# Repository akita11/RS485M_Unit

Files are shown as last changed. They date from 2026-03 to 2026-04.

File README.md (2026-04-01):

# RS485M Unit

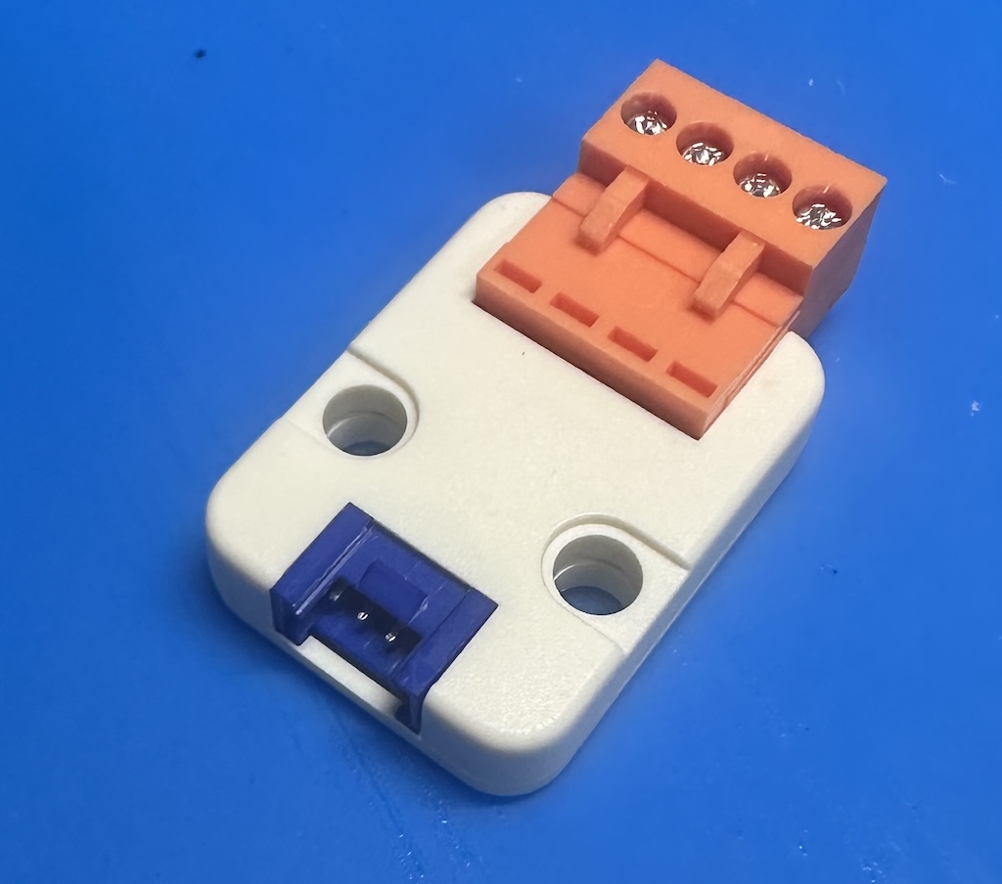
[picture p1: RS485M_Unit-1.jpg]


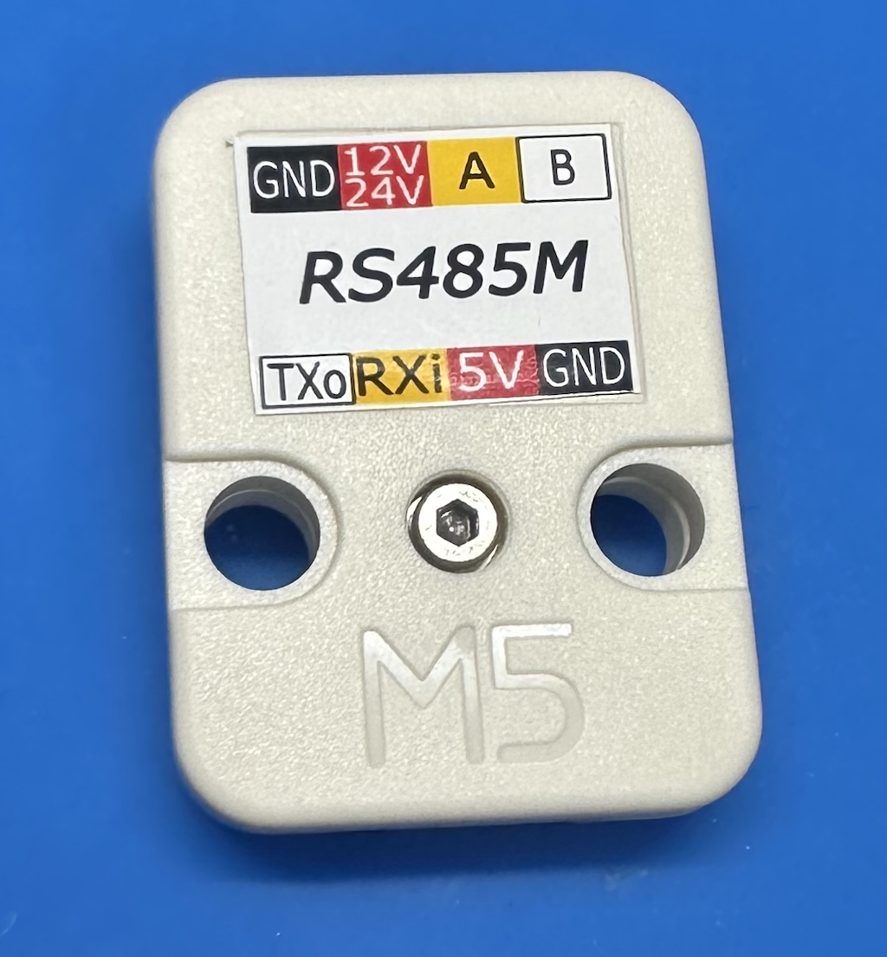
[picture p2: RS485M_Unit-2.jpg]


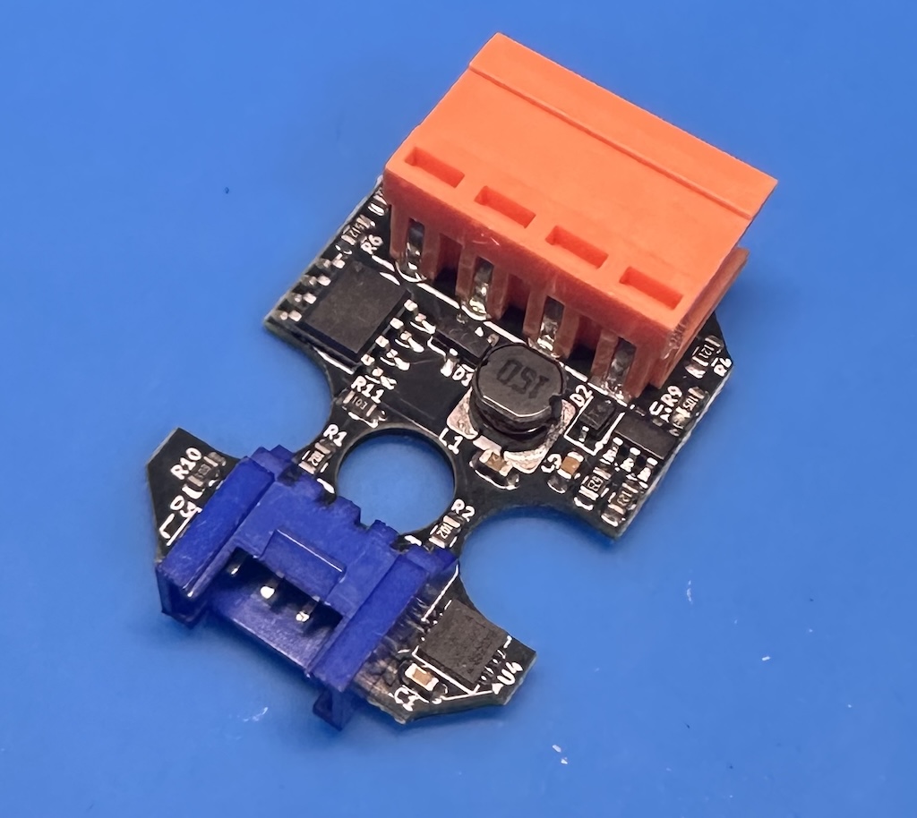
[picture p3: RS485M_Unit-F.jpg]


RS485規格の半二重シリアル通信を行うことができるUnitです。
Grove端子でM5Stackシリーズ等のマイコンと接続して使用します。

[M5Stack社のRS485 Unit](https://www.switch-science.com/products/6554)とは異なり、本来のRS485の通信仕様でマルチドロップの1:N通信トポロジを構成できます（詳細は後述）。
データを送信している期間のみ伝送路を送信駆動する制御を行います（通信速度は変更可能）。

伝送路側から最大24Vを供給してマイコン側に5Vを供給することができます。

理論上最大256台まで接続可能な低入力容量型のRS485ドライバを使用しています。

## RS485通信の基本構成と「M5Stack社のRS485 Unit」との相違点

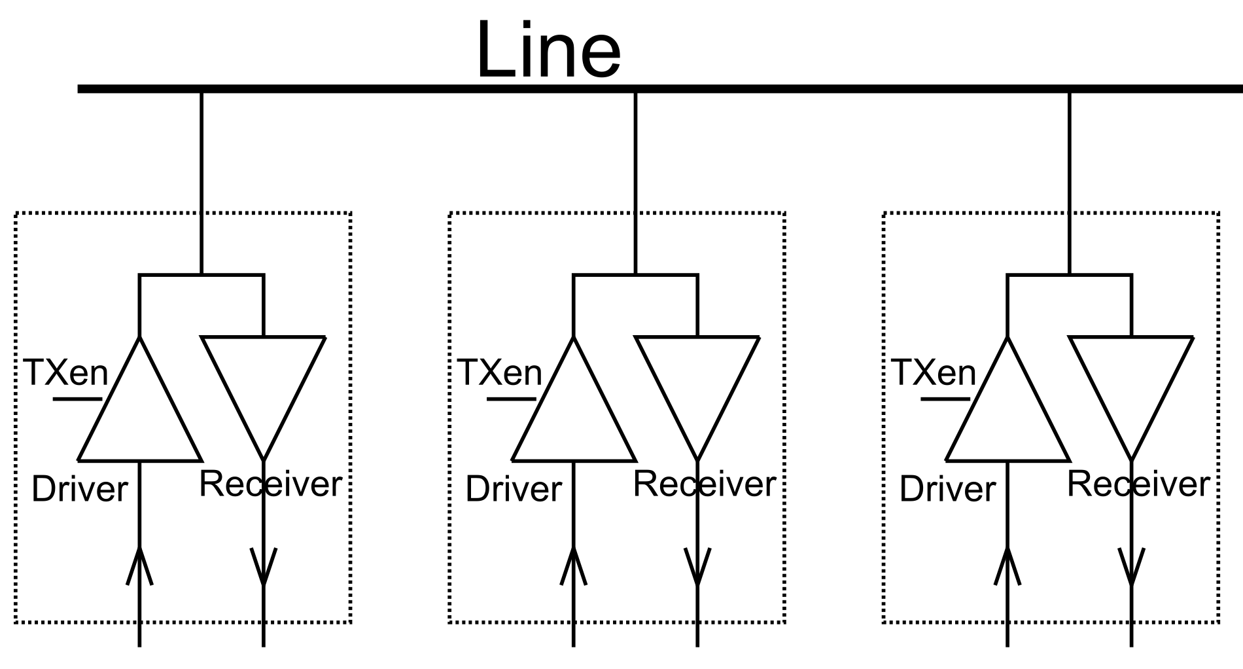
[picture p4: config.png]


RS485は、2本の伝送路(Line)を使ってシリアルデータ(UART)を送受信する規格です。
規格の詳細と、M5Stack社のRS485 Unitでの留意すべき点は[こちら](https://note.com/akita11/n/n0c082069f98c)を参照してください。

「M5Stack社のRS485 Unit」との相違点は以下です。
（以下のカッコ内の※以下は「M5Stack社のRS485 Unit」の仕様）

- 非送信時には伝送路が非駆動（※"1"で駆動）
- 送信時のみ伝送路を駆動、1バイト単位自動またはGPIOで制御（※常時"1"で駆動）
- 給電入力は48Vまで、24V給電時の過渡応答でも破損しにくい（※給電入力の絶対最大定格が30Vのため24V給電時の過渡応答で破損する場合がある）

## 使い方

基本的には[M5Stack社のRS485 Unit](https://www.switch-science.com/products/6554)と同じ使い方ですが、送信制御のみ異なり、以下の通りの仕様です。

なおJP5をショートすると伝送路の終端抵抗（120Ω）をONにできます。
またJP6とJP7をショートすると、伝送路のプルアップ・プルダウンを有効にできます（Aプルアップ、Bがプルダウン（5.1kΩ））。

### データ送信

データ送信時には、送信している期間のみDriverが自動的に有効となり、伝送路Lineを駆動します。

スタートビット検出から1バイト分（10bit分=STARTビット+データ8ビット+STOPビット）の時間だけ自動的にDriverが有効となり、伝送路にデータを送信します（伝送路を駆動中はLEDが点灯）。
通信方式はN81（8ビット・STOPビット1ビット、パリティなし）で固定です。
初期設定では通信速度は9600bpsです。

データ送信時にDriverを有効とする時間は、データ転送速度（ボーレート）に依存するため、後述の方法で変更できます

データ送信中は、Receiverは無効となり、データを受信しません。
JP8を2-3側に切り替えると、伝送路レシーバReceiverを常時有効に設定できますが、この場合は、自分のDriverが送信したデータを常時受信することになります。

### ピン配置

- p1: RXD（マイコン側の受信。本ユニットはRS485受信データの出力）
- p2: TXD（マイコン側の送信。本ユニットはRS485送信データの入力）
- p3: +5V
- p4: GND

### 伝送速度（ボーレート）の変更

Grove側からBREAK信号（一定時間以上、データ線を"L"に保持）することで、伝送速度変更モードに入り、LEDが点滅します。
この状態で、設定したい伝送速度（ボーレート）で以下のいずれか1バイトを送信することで、その波形から伝送速度を検出し、伝送速度の設定（Driverを有効とする時間）を変更します。
設定された伝送速度は電源を切っても保存されます。

- 'U' (0x55) : 1バイト伝送モード。1バイト伝送終了後の伝送路ドライバがDisableに戻ります。（LEDが3回点滅）
- '5' (0x35) : 連続伝送モード。送信開始語、一定時間データが送られなかった場合に伝送路ドライバがDisableに戻ります。（LEDが5回点滅）

なおBREAK信号は、PC用ターミナルソフトでも送出ができます（例えばTeraTermではAlt+B、MacのscreenコマンドではCtrl+A→Ctr+B）。
[Groveケーブル-USBシリアル接続ケーブル](https://www.switch-science.com/products/9460)などを使って、PCと接続して設定変更や送受信テストができます。

### 電源給電の設定

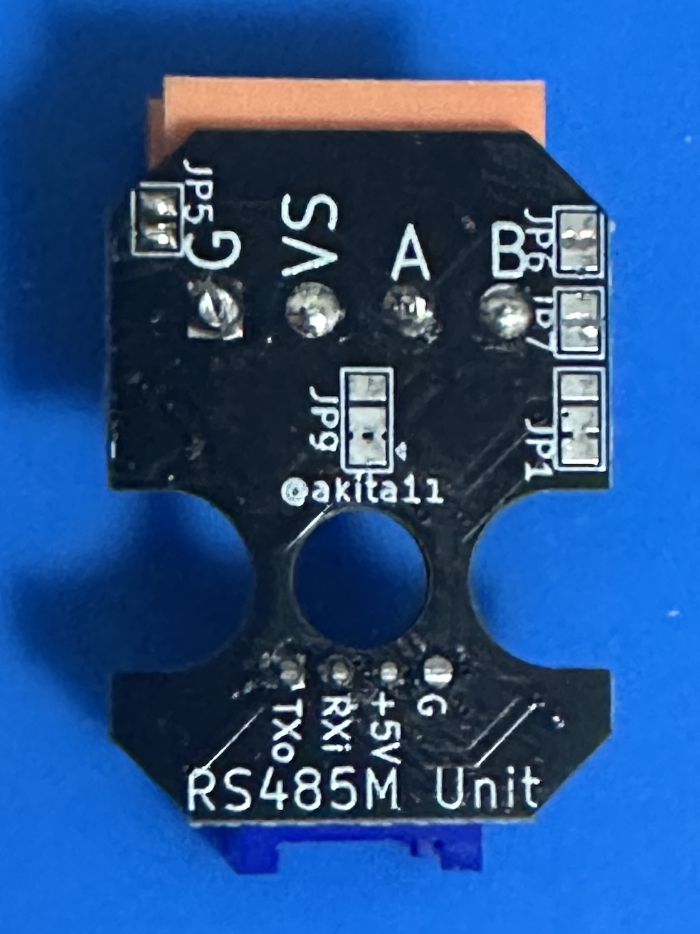
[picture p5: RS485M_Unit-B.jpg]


デフォルトでは、RS485ドライバは5V給電（外部12/24Vから生成した5V）ですが、以下のように変更できます。
なおGrove端子側から5Vを供給することもできます。

- JP9: 給電方法
  - 1-2間: 外部12/24Vから5Vを生成、本体とGroveへ供給（デフォルト）
  - 2-3間: 外部給電をそのまま本体・Groveへ接続（※この場合は外部からの給電電圧は5Vとしてください。5V以上の電圧を加えると破損する場合があります）

## Author

Junichi Akita (@akita11) / akita@ifdl.jp

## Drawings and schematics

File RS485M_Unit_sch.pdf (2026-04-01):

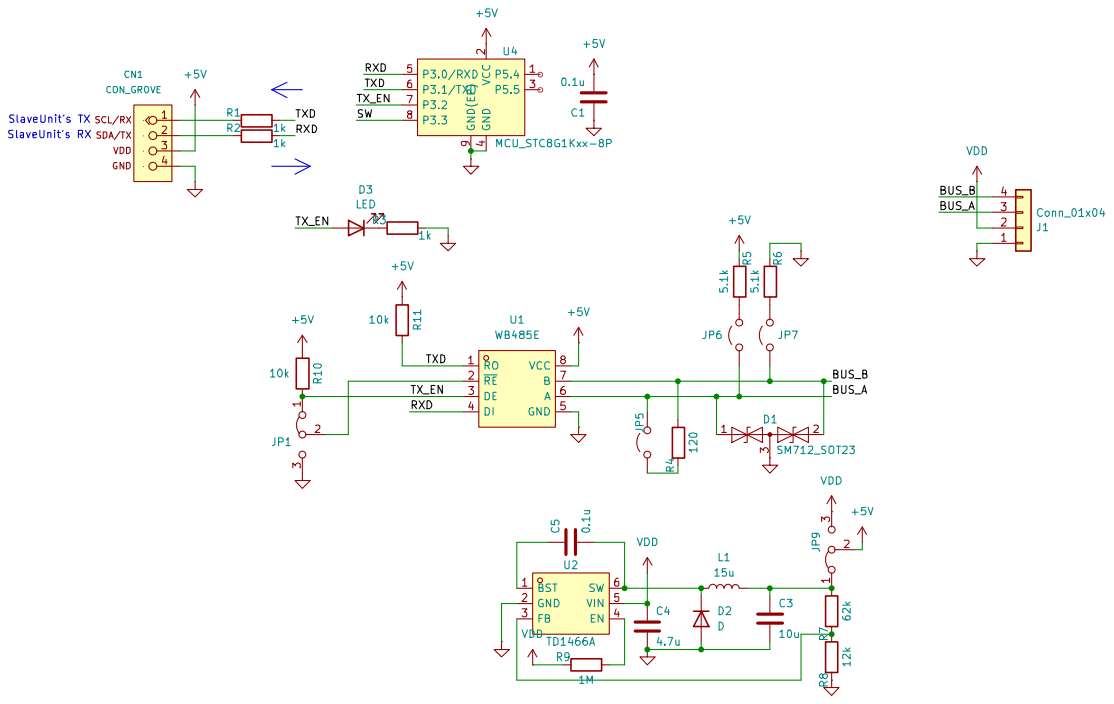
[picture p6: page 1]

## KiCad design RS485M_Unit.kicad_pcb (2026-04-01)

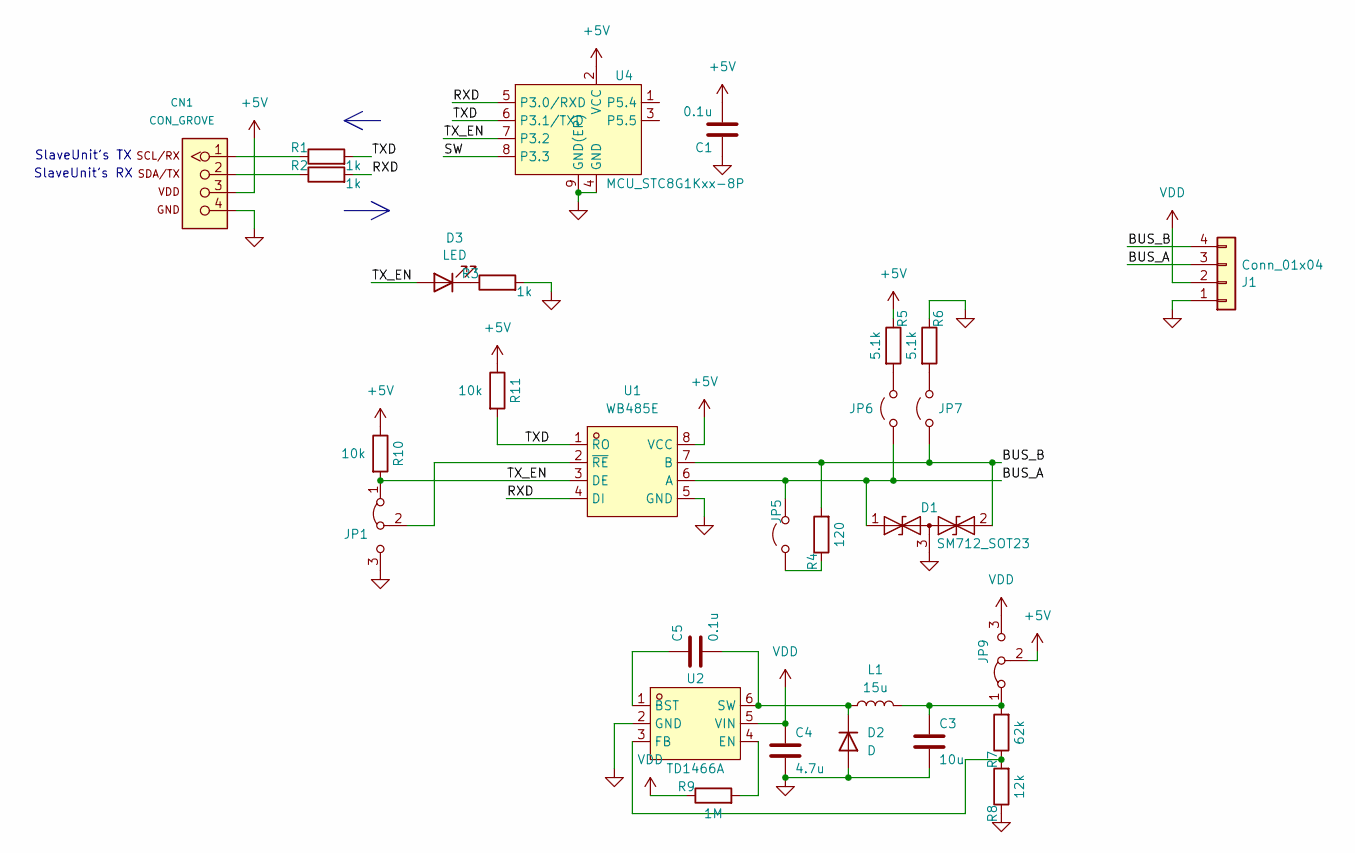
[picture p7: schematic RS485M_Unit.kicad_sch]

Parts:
C1, C5: 0.1u; C_0603_1608Metric; LCSC C14663
C3: 10u; C_0603_1608Metric; LCSC C19702
C4: 4.7u; C_0603_1608Metric; LCSC C167655
CN1: CON_GROVE; CON_GROVE_H
D1: SM712_SOT23; SOT-23; LCSC C5180237
D2: D; D_SOD-323F
D3: LED; LED_0603_1608Metric; LCSC C2286
J1: Conn_01x04; CON_HT396R_4P_hole0.8sq
JP1: Jumper_3_Bridged12; SolderJumper-3_P1.3mm_Bridged12_Pad1.0x1.5mm
JP5, JP6, JP7: Jumper_2_Open; SolderJumper-2_P1.3mm_Open_Pad1.0x1.5mm
JP9: Jumper_3_Bridged12; SolderJumper-3_P1.3mm_Bridged2Bar12_Pad1.0x1.5mm
L1: 15u; L_CD43; LCSC C5289403
R1, R2, R3: 1k; R_0603_1608Metric; LCSC C21190
R4: 120; R_0603_1608Metric; LCSC C286567
R5, R6: 5.1k; R_0603_1608Metric; LCSC C23186
R7: 62k; R_0603_1608Metric; LCSC C3017756
R8: 12k; R_0603_1608Metric; LCSC C3017713
R9: 1M; R_0603_1608Metric; LCSC C2907115
R10, R11: 10k; R_0603_1608Metric; LCSC C25804
U1: WB485E; SOIC-8_L5.0-W4.0-P1.27-LS6.0-BL; LCSC Part C42460582
U2: TD1466A; SOT-23-6_L2.9-W1.7-P0.95-LS2.8-BL; LCSC Part C51928156
U4: MCU_STC8G1Kxx-8P; DFN-8-1EP_3x3mm_P0.5mm_EP1.65x2.38mm; LCSC C915664

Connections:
+5V: C1.2, CN1.3, JP9.2 (C), R5.1, R10.1, R11.1, U1.8 (VCC), U4.2 (VCC)
/BUS_A: D1.1 (A1), J1.3, JP5.2 (B), JP6.1 (A), U1.6 (A)
/BUS_B: D1.2 (A2), J1.4, JP7.1 (A), R4.2, U1.7 (B)
/RXD: R2.2, U1.4 (DI), U4.5 (P3.0/RXD)
/SW: U4.8 (P3.3)
/TXD: R1.2, R11.2, U1.1 (RO), U4.6 (P3.1/TXD)
/TX_EN: D3.2 (A), JP1.1 (A), R10.2, U1.3 (DE), U4.7 (P3.2)
GND: C1.1, C3.2, C4.2, CN1.4, D1.3 (common), D2.2 (A), J1.1, JP1.3 (B), R3.2, R6.1, R8.1, U1.5 (GND), U2.2 (GND), U4.4 (GND), U4.9 (GND(EP))
unnamed: CN1.1, R1.1
unnamed: CN1.2, R2.1
unnamed: C5.2, D2.1 (K), L1.1, U2.6 (SW)
unnamed: D3.1 (K), R3.1
unnamed: JP1.2 (C), U1.2 (~RE)
unnamed: JP5.1 (A), R4.1
unnamed: JP6.2 (B), R5.2
unnamed: JP7.2 (B), R6.2
unnamed: C3.1, JP9.1 (A), L1.2, R7.2
unnamed: C5.1, U2.1 (BST)
unnamed: R9.2, U2.4 (EN)
unnamed: R7.1, R8.2, U2.3 (FB)
VDD: C4.1, J1.2, JP9.3 (B), R9.1, U2.5 (VIN)

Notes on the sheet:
SlaveUnit's TX
SlaveUnit's RX

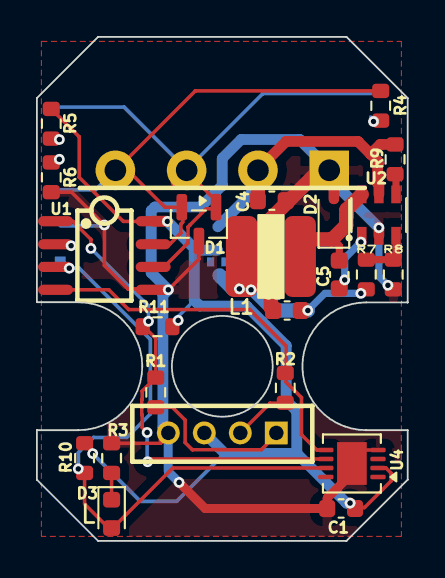
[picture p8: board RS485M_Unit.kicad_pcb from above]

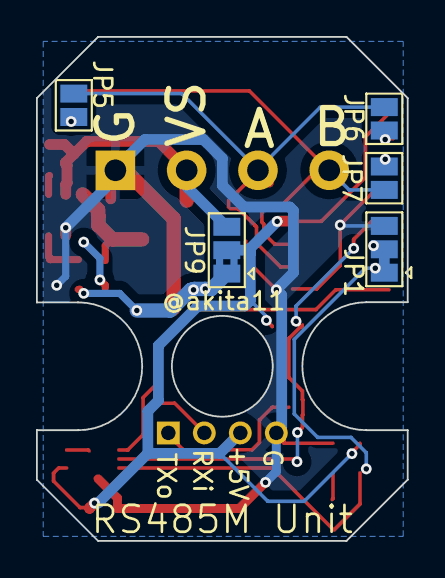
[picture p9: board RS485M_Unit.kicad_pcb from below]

Board: 2 copper layers, 20.6 x 28.0 mm, 29 parts (5 on the bottom side), 20 nets.

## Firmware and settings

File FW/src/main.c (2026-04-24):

#include <stdint.h>
#include "fw_reg_stc8g.h"

// STC8G1K08A-36I-DFN8 (ROM=8kB)
// P3.0: RXD (UART1 receive)
// P3.2: TX_EN (RS485 transmit enable, push-pull output)

#define FOSC 11059200UL

//#define DEBUG  // Uncomment to enable UART debug output during auto-baud detection

// Pin definitions
#define pinRXD  P30  // P3.0
#define pinTXEN P32  // P3.2

// SCON.7 is FE when SMOD0=1 (shares bit with SM0)
#define FE SM0

// EEPROM (IAP) definitions
#define IAP_ADDR_BASE   0x0000
#define IAP_MAGIC       0xA5
#define IAP_MAGIC2      0x5A
// Layout: [0]=MAGIC [1]=MAGIC2 [2]=bit_period_H [3]=bit_period_L [4]=txen_per_byte

// Baud rate detection timeout
#define BAUD_DETECT_TIMEOUT_MS  5000UL
#define TIMER0_OVERFLOW_MS      6UL
#define BAUD_TIMEOUT_OVERFLOWS  (BAUD_DETECT_TIMEOUT_MS / TIMER0_OVERFLOW_MS)
#define TOGGLE_PERIOD_OVERFLOWS  (500UL / TIMER0_OVERFLOW_MS)   // ~83 overflows ≈ 0.5 second

// Global variables
volatile uint16_t bit_period = FOSC / 9600;  // initial: 1152 SYSclk per bit
volatile uint8_t txen_per_byte = 1;          // 1: per-byte mode, 0: per-packet mode
volatile uint16_t baud_detect_timeout_counter = 0;
volatile uint8_t baud_detect_in_progress = 0;
volatile uint8_t do_auto_baud = 0;

void delay_cycles(uint16_t cycles)
{
  CL = 0;
  CH = 0;
  CR = 1;
  while (((uint16_t)CH << 8 | CL) < cycles);
  CR = 0;
}

void delay_ms(uint16_t ms)
{
  // 1ms ~ 11059 SYSclk cycles (@ 11.0592MHz)
  while (ms--) {
    delay_cycles(11059);
  }
}

// IAP (EEPROM) functions
void iap_idle(void)
{
  IAP_CONTR = 0;
  IAP_CMD = 0;
  IAP_TRIG = 0;
  IAP_ADDRH = 0x80;  // point to non-existent address
  IAP_ADDRL = 0;
}

uint8_t iap_read(uint16_t addr)
{
  IAP_CONTR = 0x80;      // IAPEN=1
  IAP_TPS = 11;          // FOSC=11.0592MHz -> 11
  IAP_CMD = 1;           // read
  IAP_ADDRH = addr >> 8;
  IAP_ADDRL = addr & 0xFF;
  IAP_TRIG = 0x5A;
  IAP_TRIG = 0xA5;
  NOP();
  {
    uint8_t val = IAP_DATA;
    iap_idle();
    return val;
  }
}

void iap_write(uint16_t addr, uint8_t dat)
{
  IAP_CONTR = 0x80;
  IAP_TPS = 11;
  IAP_CMD = 2;           // write
  IAP_ADDRH = addr >> 8;
  IAP_ADDRL = addr & 0xFF;
  IAP_DATA = dat;
  IAP_TRIG = 0x5A;
  IAP_TRIG = 0xA5;
  NOP();
  iap_idle();
}

void iap_erase(uint16_t addr)
{
  IAP_CONTR = 0x80;
  IAP_TPS = 11;
  IAP_CMD = 3;           // erase (512-byte sector)
  IAP_ADDRH = addr >> 8;
  IAP_ADDRL = addr & 0xFF;
  IAP_TRIG = 0x5A;
  IAP_TRIG = 0xA5;
  NOP();
  iap_idle();
}

void eeprom_save_baud(void)
{
  EA = 0;
  iap_erase(IAP_ADDR_BASE);
  iap_write(IAP_ADDR_BASE + 0, IAP_MAGIC);
  iap_write(IAP_ADDR_BASE + 1, IAP_MAGIC2);
  iap_write(IAP_ADDR_BASE + 2, bit_period >> 8);
  iap_write(IAP_ADDR_BASE + 3, bit_period & 0xFF);
  iap_write(IAP_ADDR_BASE + 4, txen_per_byte);
  EA = 1;
}

void eeprom_load_baud(void)
{
  if (iap_read(IAP_ADDR_BASE + 0) == IAP_MAGIC &&
      iap_read(IAP_ADDR_BASE + 1) == IAP_MAGIC2) {
    uint16_t bp = ((uint16_t)iap_read(IAP_ADDR_BASE + 2) << 8)
                | iap_read(IAP_ADDR_BASE + 3);
    // Validate: FOSC/115200 <= bp <= FOSC/300
    if (bp < (uint16_t)(FOSC / 115200UL) || bp > (uint16_t)(FOSC / 300UL)) return;
    bit_period = bp;
    uint8_t mode = iap_read(IAP_ADDR_BASE + 4);
    if (mode <= 1) txen_per_byte = mode;
    uint16_t reload = 65536U - (bit_period / 4U);
    TH1 = reload >> 8;
    TL1 = reload & 0xFF;
  }
}

#ifdef DEBUG
// UART debug output helpers
void uart_send_byte(uint8_t dat)
{
  uint16_t tout;
  SBUF = dat;
  for (tout = 60000U; !TI && tout; tout--);
  if (!TI) {
    // TI never set: Timer2/UART TX broken -> blink P3.2 rapidly as error signal
    while (1) {
      uint16_t _d;
      pinTXEN ^= 1;
      for (_d = 0; _d < 5000; _d++) NOP();  // ~500us per half-cycle -> ~1kHz blink
    }
  }
  TI = 0;
}

void uart_send_string(const char *str)
{
  while (*str) {
    uart_send_byte(*str++);
  }
}

void uart_send_hex_byte(uint8_t val)
{
  const char hex[] = "0123456789ABCDEF";
  uart_send_byte(hex[val >> 4]);
  uart_send_byte(hex[val & 0x0F]);
}

void uart_send_hex_word(uint16_t val)
{
  uart_send_hex_byte(val >> 8);
  uart_send_hex_byte(val & 0xFF);
}
#endif /* DEBUG */

void auto_baud_detect(void);

// INT4 ISR: P3.0 falling edge (start bit detection)
void INT4_ISR(void) __interrupt (16)
{
  pinTXEN = 1;
  AUXINTIF &= ~0x40;  // clear INT4 interrupt flag
  INTCLKO &= ~0x40;   // disable INT4
#ifdef DEBUG
  uart_send_byte('I');  // INT4 fired
#endif

  if (!txen_per_byte) {
    // Packet mode: stop timeout timer (next byte arrived in time)
    TR0 = 0;
  }
}

// Timer0 ISR: packet timeout OR baud detection timeout
void Timer0_ISR(void) __interrupt (1)
{
  if (baud_detect_in_progress) {
    // Baud detection timeout mode
    baud_detect_timeout_counter++;
    if (baud_detect_timeout_counter >= BAUD_TIMEOUT_OVERFLOWS) {
      TR0 = 0;  // Stop timer when timeout reached
    }
    // Note: Timer continues counting until timeout is reached
  } else {
    // Normal packet timeout mode
    TR0 = 0;
    if (!txen_per_byte) {
      pinTXEN = 0;
    }
  }
}

// UART1 ISR: RI or FE
void UART1_ISR(void) __interrupt (4)
{
  volatile uint8_t dummy;
  if (FE) {
    FE = 0;
    dummy = SBUF;
    (void)dummy;
    // BREAK = FE + received 0x00 + RXD still Low
    if (dummy == 0x00 && pinRXD == 0) {
#ifdef DEBUG
      uart_send_byte('B');  // BREAK detected → do_auto_baud
#endif
      pinTXEN = 0;
      INTCLKO &= ~0x40;  // disable INT4
      do_auto_baud = 1;  // defer to main loop (Timer0 ISR can't run in ISR context)
      return;            // return immediately; INT4 re-enabled by auto_baud_detect()
    }
#ifdef DEBUG
    uart_send_byte('F');  // FE (non-BREAK)
#endif
    // Non-BREAK FE: re-enable INT4
    pinTXEN = 0;
    AUXINTIF &= ~0x40;
    INTCLKO |= 0x40;
    return;
  }
  if (RI) {
    RI = 0;
    dummy = SBUF;       // read received data
    (void)dummy;
#ifdef DEBUG
    uart_send_byte('R');  // RI fired
#endif

    if (txen_per_byte) {
      // Per-byte mode: turn off TX_EN, re-enable INT4
      // Note: delay removed - RI fires at mid-stop-bit, sufficient for TX_EN deassertion
      pinTXEN = 0;
      AUXINTIF &= ~0x40;
      INTCLKO |= 0x40;
#ifdef DEBUG
      uart_send_byte('X');  // per-byte: TXen cleared
#endif
    } else {
#ifdef DEBUG
      uart_send_byte('P');  // per-packet path
#endif
      // Per-packet mode: re-enable INT4, start timeout timer
      AUXINTIF &= ~0x40;
      INTCLKO |= 0x40;

      // Reconfigure Timer0 for packet timeout (1.5 bit period)
      {
        uint16_t timeout = bit_period + (bit_period >> 1);  // 1.5 * bit_period
        uint16_t reload = 65536 - timeout;
        TH0 = reload >> 8;
        TL0 = reload & 0xFF;
      }
      TF0 = 0;
      TR0 = 1;
    }
  }
}

// Auto-baud detection using BREAK + single byte (0x55/0x35) pattern
// Measures 5 bit periods, reads D5/D6 to determine mode, blinks LED (3 or 5 times), then applies baud rate
void auto_baud_detect(void)
{
  uint16_t t_start, t_end;
  uint16_t old_bit_period = bit_period;
  uint8_t old_txen_per_byte = txen_per_byte;
#ifdef DEBUG
  uint8_t bit_period_measured = 0;  // Track if bit_period was measured
  uint8_t d5d6_measured = 0;        // Track if D5/D6 were read
#endif
  uint8_t d5_bit = 0;               // D5 bit value
  uint8_t d6_bit = 0;               // D6 bit value
  uint16_t last_toggle_counter = 0;

  REN = 0;
  INTCLKO &= ~0x40;
  pinTXEN = 1;  // Hold TXEN during baud rate measurement
  TR0 = 0;

  // Configure Timer0 for 5-second baud detection timeout
  baud_detect_in_progress = 1;
  baud_detect_timeout_counter = 0;
  TH0 = 0;
  TL0 = 0;
  TF0 = 0;
  TR0 = 1;  // Start timeout timer

  TR1 = 0;           // Stop Timer1 UART clock before reconfiguring for measurement

  // Timer1: 16-bit free-run, 1T mode
  TMOD = (TMOD & 0x0F) | 0x00;
  AUXR |= 0x40;  // T1x12=1

  TH1 = 0; TL1 = 0;
  TF1 = 0;
  TR1 = 1;

  // Wait for BREAK to end (RXD goes high)
  while (pinRXD == 0) {
    if (baud_detect_timeout_counter >= BAUD_TIMEOUT_OVERFLOWS) {
      goto abort;
    }
  }

  // Wait for falling edge (start bit)
  while (pinRXD == 1) {
    if (baud_detect_timeout_counter >= BAUD_TIMEOUT_OVERFLOWS) goto abort;
    if ((uint16_t)(baud_detect_timeout_counter - last_toggle_counter) >= TOGGLE_PERIOD_OVERFLOWS) {
      pinTXEN ^= 1;  // Toggle every ~1 second to show loop is running
      last_toggle_counter = baud_detect_timeout_counter;
    }
  }
  t_start = ((uint16_t)TH1 << 8) | TL1;

  // Measure 5 bit periods: S(0)->D0(1)->D1(0)->D2(1)->D3(0)->D4(1)
  // S(0)→D0(1)
  while (pinRXD == 0) {
    if (baud_detect_timeout_counter >= BAUD_TIMEOUT_OVERFLOWS) goto abort;
  }
  // D0(1)→D1(0)
  while (pinRXD == 1) {
    if (baud_detect_timeout_counter >= BAUD_TIMEOUT_OVERFLOWS) goto abort;
  }
  // D1(0)→D2(1)
  while (pinRXD == 0) {
    if (baud_detect_timeout_counter >= BAUD_TIMEOUT_OVERFLOWS) goto abort;
  }
  // D2(1)→D3(0)
  while (pinRXD == 1) {
    if (baud_detect_timeout_counter >= BAUD_TIMEOUT_OVERFLOWS) goto abort;
  }
  // D3(0)→D4(1)
  while (pinRXD == 0) {
    if (baud_detect_timeout_counter >= BAUD_TIMEOUT_OVERFLOWS) goto abort;
  }

  // Capture t_end; compute D5/D6 sample thresholds with shifts BEFORE expensive division
  t_end = ((uint16_t)TH1 << 8) | TL1;
  {
    uint16_t span = t_end - t_start;               // = 5T (subtraction only, ~2 cycles)
    uint16_t thr_d5 = (span >> 2) + (span >> 4);  // = 5/16 * span ≈ 1.5625T (within D5 window)
    uint16_t thr_d6 = span >> 1;                  // = 1/2 * span = 2.5T (exact D6 midpoint)
    uint16_t now_t;

    // Wait until middle of D5 bit period
    do {
      if (baud_detect_timeout_counter >= BAUD_TIMEOUT_OVERFLOWS) goto abort;
      now_t = ((uint16_t)TH1 << 8) | TL1;
    } while ((uint16_t)(now_t - t_end) < thr_d5);
    d5_bit = pinRXD;

    // Wait until middle of D6 bit period
    do {
      if (baud_detect_timeout_counter >= BAUD_TIMEOUT_OVERFLOWS) goto abort;
      now_t = ((uint16_t)TH1 << 8) | TL1;
    } while ((uint16_t)(now_t - t_end) < thr_d6);
    d6_bit = pinRXD;

    // Compute bit_period AFTER timing-critical sampling section
    bit_period = span / 5;
#ifdef DEBUG
    bit_period_measured = 1;
#endif
  }
#ifdef DEBUG
  d5d6_measured = 1;  // Mark as measured
#endif

  // Validate bit pattern and set mode
  if (d5_bit == 0 && d6_bit == 1) {
    // Pattern 01 → 0x55 → per-byte mode
    txen_per_byte = 1;
  } else if (d5_bit == 1 && d6_bit == 0) {
    // Pattern 10 → 0x35 → per-packet mode
    txen_per_byte = 0;
  } else {
    // Invalid pattern → abort
    goto abort;
  }

  // Stop Timer1 (measurement done)
  TR1 = 0;

  // Restore Timer1 for UART baud at old bit_period (needed for BP_PRE debug output)
  {
    uint16_t _r = 65536U - (old_bit_period / 4U);
    TH1 = _r >> 8;
    TL1 = _r & 0xFF;
    TR1 = 1;
  }

  // Stop timeout timer before blinking
  TR0 = 0;
  baud_detect_in_progress = 0;

  // Blink pinTXEN: 3 times for per-byte mode (0x55), 5 times for per-packet mode (0x35)
  // (100ms ON, 100ms OFF)
  {
    uint8_t i;
    uint8_t blink_count = txen_per_byte ? 3 : 5;  // 3 for mode=1, 5 for mode=0
    for (i = 0; i < blink_count; i++) {
      pinTXEN = 1;
      delay_ms(100);
      pinTXEN = 0;
      delay_ms(100);
    }
  }

  // Send BP_PRE at old baud rate for diagnosis (before Timer2 is updated)
#ifdef DEBUG
  uart_send_string("BP_PRE:");
  uart_send_hex_word(bit_period);
  uart_send_string("\r\n");
#endif

  // Apply new baud rate to Timer1
  {
    uint16_t reload = 65536U - (bit_period / 4U);
    TH1 = reload >> 8;
    TL1 = reload & 0xFF;
    // TR1 already running; new reload takes effect at next overflow
  }

  // Send all debug messages at new baud rate
#ifdef DEBUG
  uart_send_string("START\r\n");
  uart_send_string("BP:");
  uart_send_hex_word(bit_period);
  uart_send_string("\r\n");
  uart_send_string("D56:");
  uart_send_hex_byte(d5_bit);
  uart_send_hex_byte(d6_bit);
  uart_send_string("\r\n");
  uart_send_string("OK:MODE=");
  uart_send_hex_byte(txen_per_byte);
  uart_send_string("\r\n");
#endif

  // Save to EEPROM
  eeprom_save_baud();
  goto resume;

abort:
  // CRITICAL: Turn off TXEN immediately to fix timeout issue
  pinTXEN = 0;

  // Stop timers
  TR0 = 0;
  TR1 = 0;
  baud_detect_in_progress = 0;

  // Restore Timer1 for UART baud at old bit_period (for abort debug output)
  {
    uint16_t _r = 65536U - (old_bit_period / 4U);
    TH1 = _r >> 8;
    TL1 = _r & 0xFF;
    TR1 = 1;
  }

  // Display measured bit_period BEFORE restoring old value (UART still at old baud rate)
#ifdef DEBUG
  if (bit_period_measured) {
    uart_send_string("BP:");
    uart_send_hex_word(bit_period);
    uart_send_string("\r\n");
  }
#endif

  // Restore previous baud rate and mode
  bit_period = old_bit_period;
  txen_per_byte = old_txen_per_byte;

  // Send all debug messages at restored baud rate
#ifdef DEBUG
  uart_send_string("START\r\n");

  if (!bit_period_measured) {
    uart_send_string("BP:NONE\r\n");
  }

  if (d5d6_measured) {
    uart_send_string("D56:");
    uart_send_hex_byte(d5_bit);
    uart_send_hex_byte(d6_bit);
    uart_send_string("\r\n");
  } else {
    uart_send_string("D56:NONE\r\n");
  }

  uart_send_string("ABORT:TO=");
  uart_send_hex_word(baud_detect_timeout_counter);
  uart_send_string("\r\n");
#endif

resume:
  // Resume normal operation
  REN = 1;
  pinTXEN = 0;
  AUXINTIF &= ~0x40;
  INTCLKO |= 0x40;  // re-enable INT4
}

void main(void)
{
  // GPIO: P3.2 quasi-bidirectional (HiZ) initially; push-pull set after TX pin is finalized
#ifdef DEBUG
  P3M1 = 0x00;
  P3M0 = 0x02;  // P3.1 push-pull (TXD for debug); P3.2 quasi-bidirectional for now
  P3M0 |= 0x04; // P3.2 push-pull (TXen) - set after P3.1 push-pull confirmed
#else
  P3M1 = 0x02;  // P3.1 high-Z input
  P3M0 = 0x00;  // P3.2 quasi-bidirectional; push-pull set after TX HiZ confirmed (below)
#endif
  P5M1 = 0x00;
  P5M0 = 0x00;  // P5.4, P5.5 quasi-bidirectional
  pinTXEN = 0;

  // Pull-up on unused pins: P3.1, P3.3, P5.4, P5.5
  P_SW2 |= 0x80;  // enable extended SFR access
#ifdef DEBUG
  P3PU = 0x0A;     // P3.1 (TXD), P3.3 pull-up
#else
  P3PU = 0x08;     // P3.3 pull-up only (P3.1 input, no pull-up)
#endif
  P5PU = 0x30;     // P5.4, P5.5 pull-up
  P_SW2 &= ~0x80;

  // PCA: for precise delay (SYSCLK/1, no interrupts)
  CMOD = 0x08;  // CPS=100: SYSCLK/1

  // UART1 pin routing: RXD=P3.0, TXD=P3.1 (explicit, in case ISP left P_SW1 non-default)
  P_SW1 &= ~0xC0;  // S1_S[1:0]=00 -> UART1 on P3.0/P3.1

  // UART1: Mode 1 (8-bit variable baud), REN=1
  // SMOD0=1 -> SCON.7 = FE (frame error flag)
  PCON |= 0x40;   // SMOD0=1
  SCON = 0x50;     // SM1=1, REN=1

  // UART1 baud generator: Timer1 Mode 0 (16-bit auto-reload), 1T
  // S1ST2=0: UART1 uses Timer1 (clear AUXR.0)
  // T1x12=1: 1T mode (AUXR.6)
  // Timer1 Mode 0 (TMOD[7:4]=0x00): 16-bit auto-reload (STC8G specific)
  // baud = FOSC / (4 * (65536 - reload)), reload = 65536 - bit_period/4
  // 9600bps @ 11.0592MHz: reload = 65536 - 288 = 65248 = 0xFEE0
  AUXR &= ~0x01;   // S1ST2=0: UART1 uses Timer1
  AUXR |= 0x40;    // T1x12=1: 1T mode
  TMOD &= 0x0F;    // Timer1 Mode 0 (16-bit auto-reload)
  TH1 = 0xFE;
  TL1 = 0xE0;      // reload = 65248 for 9600bps  (4分周, Timer2 と同じ値)
  TR1 = 1;

#ifndef DEBUG
  // P3.1 HiZ re-assert after UART init: P_SW1 routes UART TX here, but
  // STC8G GPIO high-Z disables the output driver, preventing TX from driving the pin
  P3M1 |= 0x02;
  P3M0 &= ~0x02;
  P3M0 |= 0x04; // P3.2 push-pull (TXen) - set after TX HiZ confirmed
#endif

  // Load saved baud rate from EEPROM (overrides default if valid)
  eeprom_load_baud();

#ifdef DEBUG
  // Checkpoint A: 2 pulses on P3.2 to confirm code reached uart_send_string
  {
    uint8_t _cp;
    for (_cp = 0; _cp < 2; _cp++) {
      pinTXEN = 1;
      { uint16_t _d; for (_d = 0; _d < 3000; _d++) NOP(); }  // ~300us @11MHz
      pinTXEN = 0;
      { uint16_t _d; for (_d = 0; _d < 3000; _d++) NOP(); }
    }
  }
  uart_send_string("ST:BP=");
  uart_send_hex_word(bit_period);
  uart_send_string(",M=");
  uart_send_hex_byte(txen_per_byte);
  uart_send_string("\r\n");
#endif

  // Packet mode startup notification: toggle pinTXEN 3 times
  if (!txen_per_byte) {
    uint8_t i;
    for (i = 0; i < 3; i++) {
      pinTXEN = 1;
      delay_ms(100);
      pinTXEN = 0;
      delay_ms(100);
    }
  }

  // Timer0: 16-bit mode, 1T (packet timeout)
  TMOD = (TMOD & 0xF0) | 0x00;  // Timer0 Mode 0 (16-bit auto-reload)
  AUXR |= 0x80;                  // T0x12=1 (1T mode)
  TR0 = 0;

  // INT4: falling edge on P3.0
  INTCLKO |= 0x40;  // EX4=1

  // Enable interrupts
  EA = 1;
  ES = 1;            // UART1 interrupt
  ET0 = 1;           // Timer0 interrupt (packet timeout)

  while (1) {
    if (do_auto_baud) {
      do_auto_baud = 0;
      auto_baud_detect();
    }
  }
}

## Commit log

2026-04-01 add pin assign
2026-04-01 add photo, JP6/7 modify
    [RS485M_Unit.kicad_pcb, RS485M_Unit.kicad_sch]
